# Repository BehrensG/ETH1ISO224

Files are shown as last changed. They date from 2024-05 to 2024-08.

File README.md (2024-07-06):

<h1>ETH1ISO224</h1>

ETH1ISO224 is a one-channel data acquisition card based on the ISO224 chip. The communication with a PC is over Ethernet. The card supports LAN eXtensions for Instrumentation (LXI) and RAW TCP and UDP connections.

> [!CAUTION]
> This design is still in verification phase. The device requires a calibration and validation to be done.

<h2>DESCRIPTION</h2>

<h3>Device Design</h3>

Key features of the design include:

<ul>
    <li><b>Dimensions</b>: 100 x 45 mm</li>
    <li><b>Power Supply</b>: Operates on a voltage range from 6.5 to 36 VDC (recommended 24 VDC) and includes reverse voltage protection.</li>
    <li><b>Isolation</b>: The ISO224 chip with TBA 1-0513HI provides isolation protection for the rest of the circuit.</li>
    <li><b>MCU</b>: The STM32H743VITx was selected because of its large internal FLASH and RAM memory, support for Ethernet, and internal 16-bit ADC.</li>
    <li><b>ADC</b>: Internal 16 bit ADC, configured in differential mode.</li>
    <li><b>Software</b>: FreeRTOS with lwip and SCPI parser library.</li>
</ul>

<p align="center">3D model rendition for PCB V1.2.</p>
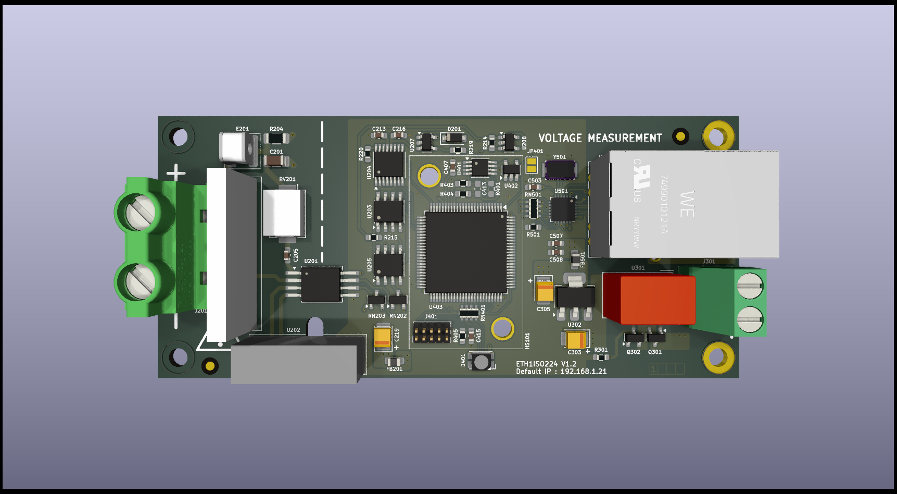
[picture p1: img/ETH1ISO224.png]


<p align="center">Below are the images for the PCB V1.0.</p>


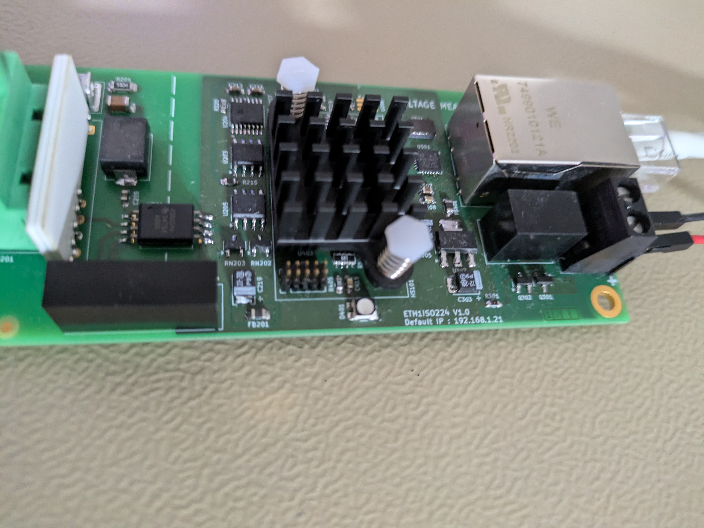
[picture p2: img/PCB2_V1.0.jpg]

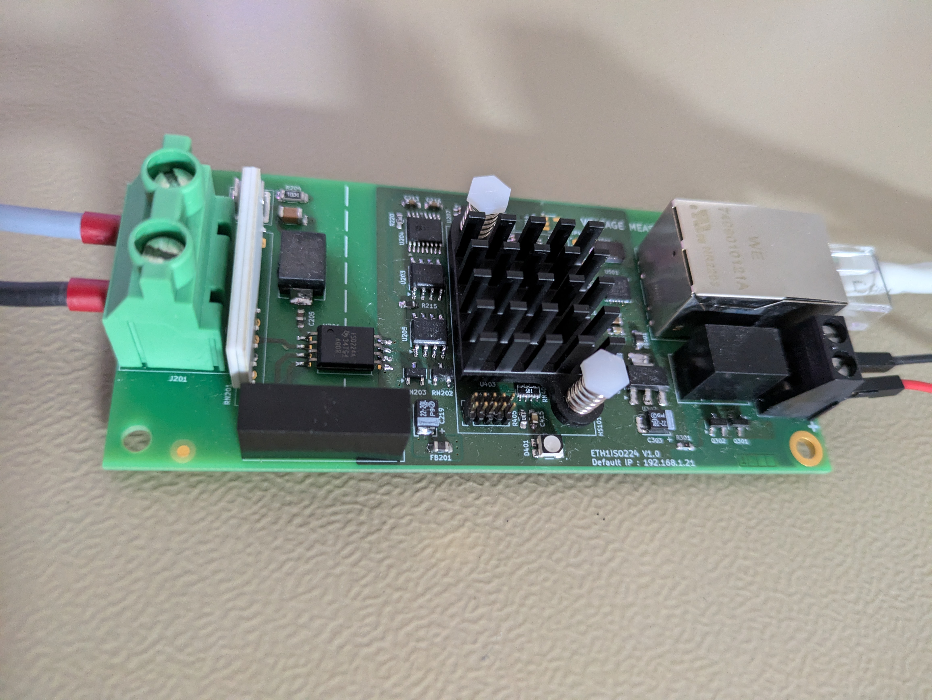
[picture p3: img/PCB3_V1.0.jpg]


<h3>Input voltage</h3>

The PCB was designed for max bipolar 1000V DC measurements. It will divide the input voltage by 100. The user can use 1776-C68xx or SMD resistors to create the voltage divider.

> [!CAUTION]
> The PCB is still in verification. There are no guarantees that it can handle 1000 VDC safely.

<h2>Ethernet connection</h2>

The PCB uses Ethernet to communicate with the PC. The features are :

<h3>LAN eXtensions for Instrumentation (LXI)</h3>

LAN eXtensions for Instrumentation (LXI) is a standard for connecting and controlling test and measurement instruments via Ethernet. It allows for easy integration, remote access, and simplified configuration, enhancing the flexibility and scalability of automated test systems.

> [!WARNING]  
> This device does not guarantee full compliance with the LXI standard. The implementation was based on available documentation and observations of an LXI-compliant device.

> [!TIP]
> To use the LXI features the user needs to use a VISA API. In the examples below, the R&S VISA Tools where uses. 

<h4><p align="center">Device autodetect with multicast DNS (mDNS).</p></h4>
<hr>
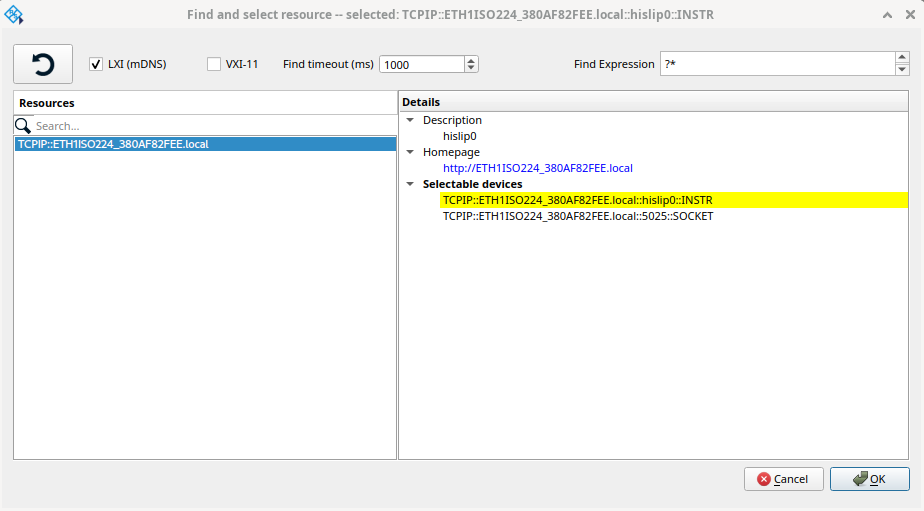
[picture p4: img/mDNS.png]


<h4><p align="center">Support for High Speed LAN Instrument Protocol (HiSLIP).</p></h4>
<hr>
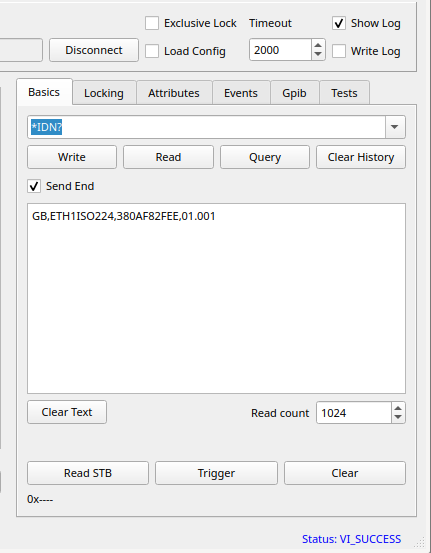
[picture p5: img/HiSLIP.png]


<h4><p align="center">Web interface</p></h4>
<hr>
The device website provides the ability to obtain device information, make measurements, and configure the device. Additionally, it offers a manual with all SCPI commands.

> [!WARNING]
> The website was tested only with Google Chrome  Browser.

<h5><p align="center">Device Home Page</p></h5>
<hr>
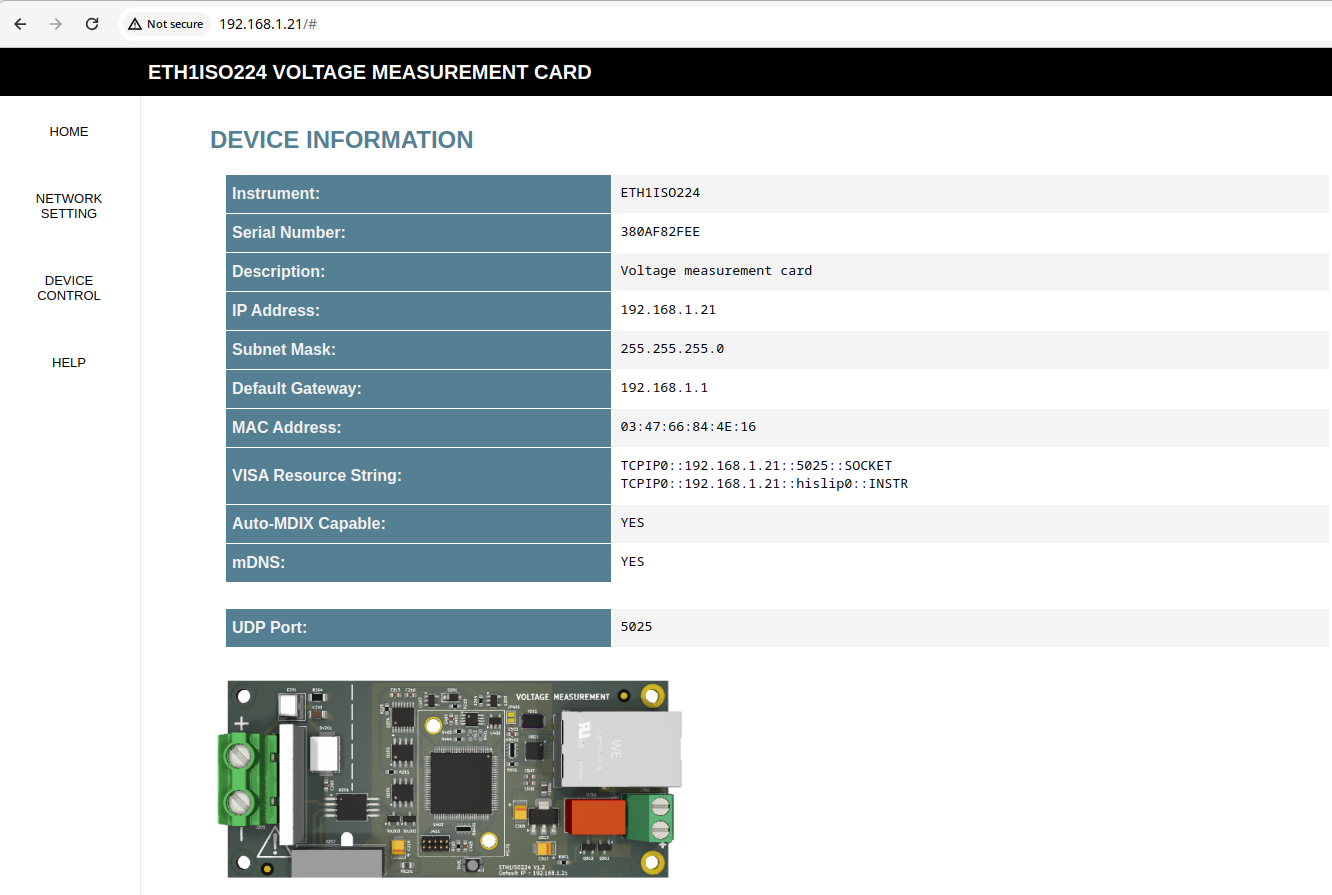
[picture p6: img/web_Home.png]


<h5><p align="center">Device Network Setup</p></h5>
<hr>
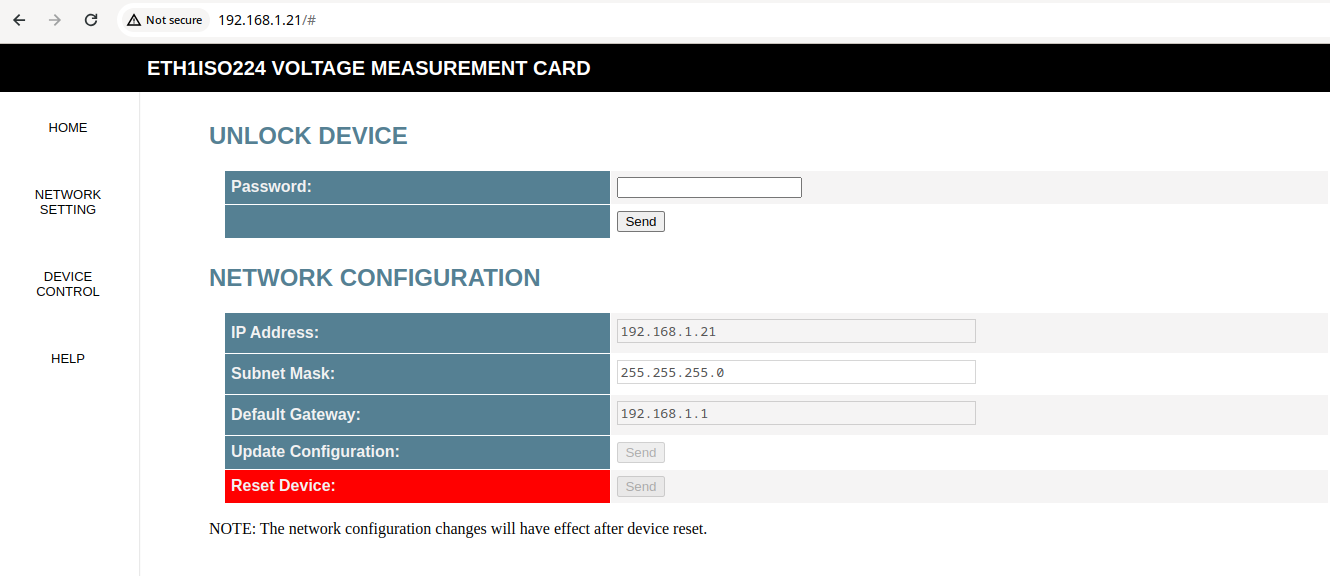
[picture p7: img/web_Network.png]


<h5><p align="center">Device Control</p></h5>
<hr>
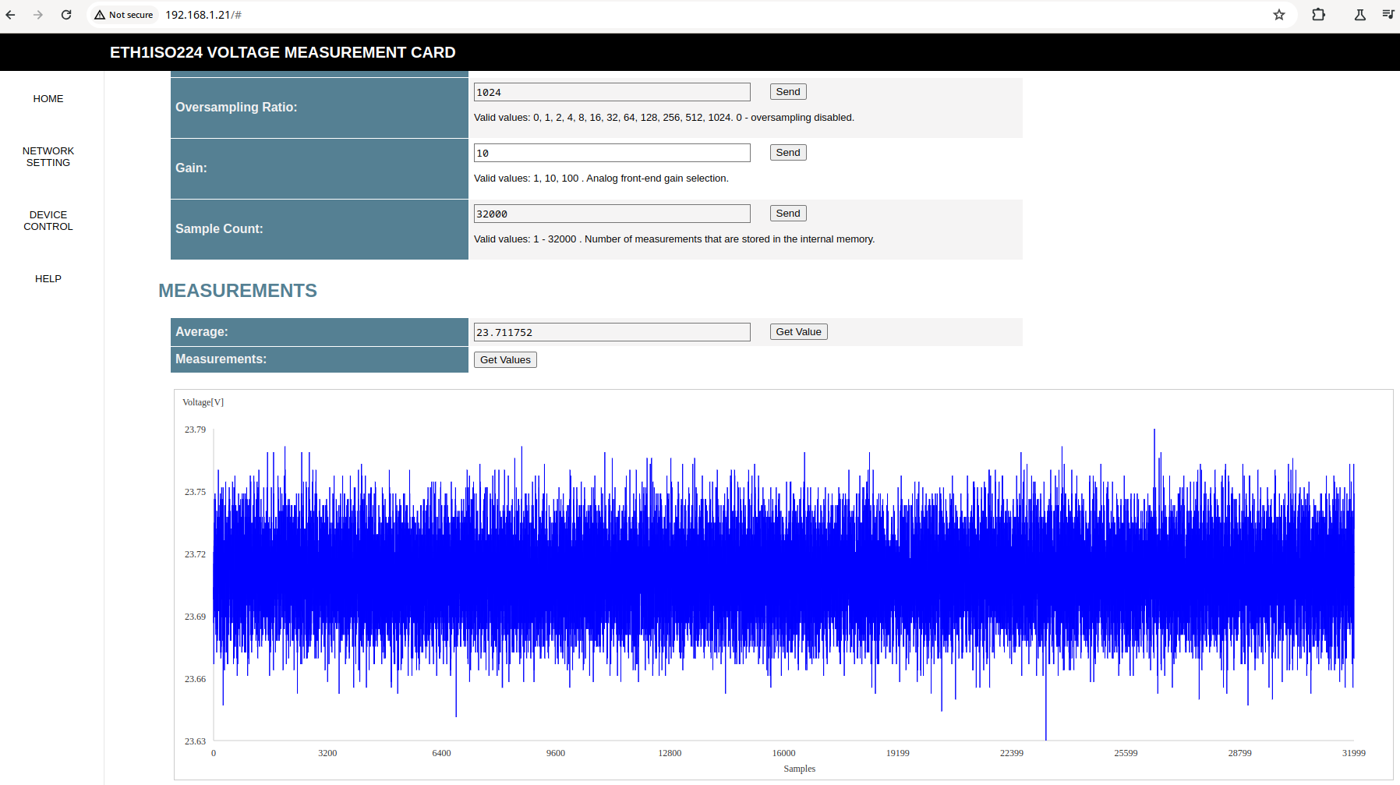
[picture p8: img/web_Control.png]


<h5><p align="center">Device Help</p></h5>
<hr>
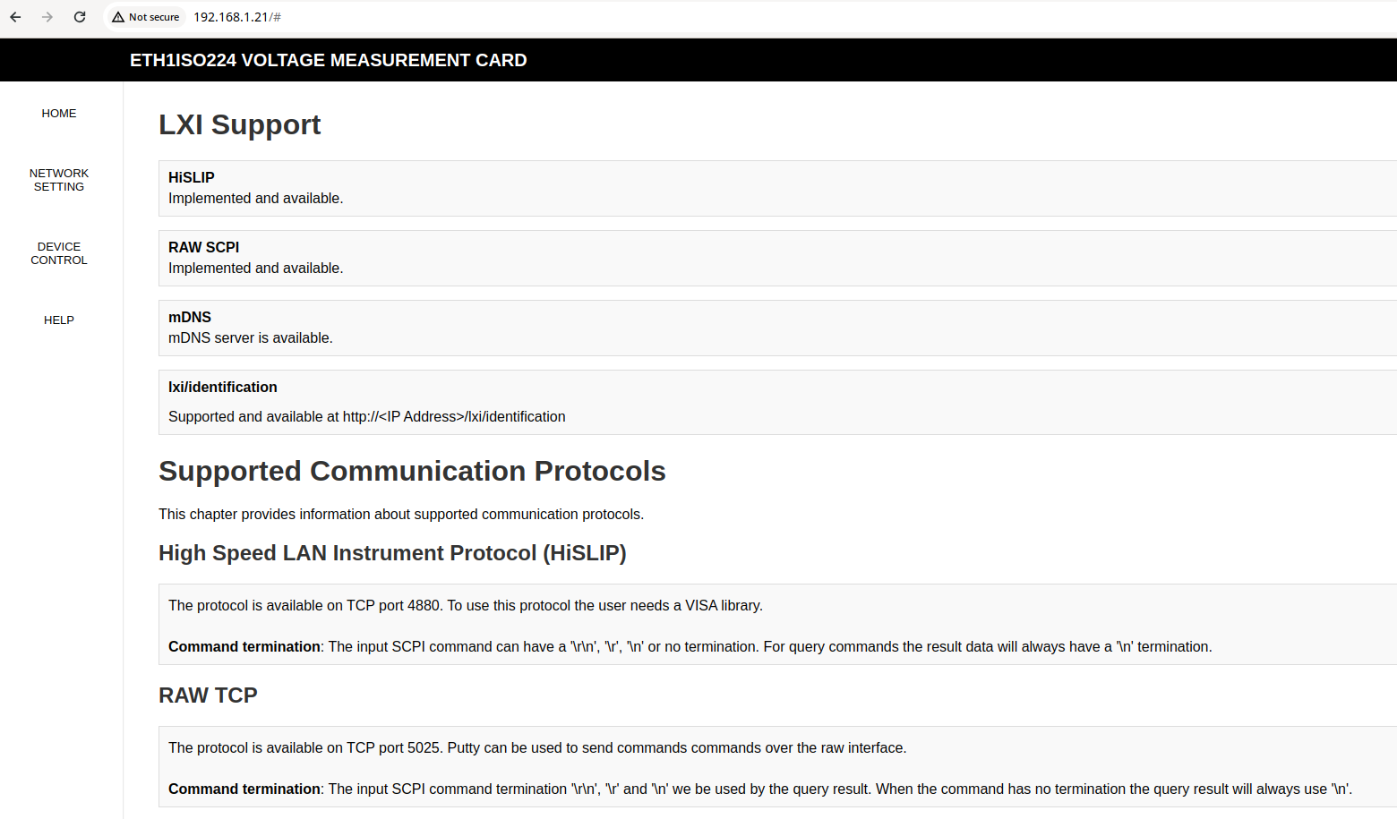
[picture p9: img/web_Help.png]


<h5><p align="center">Device Service</p></h5>
<hr>
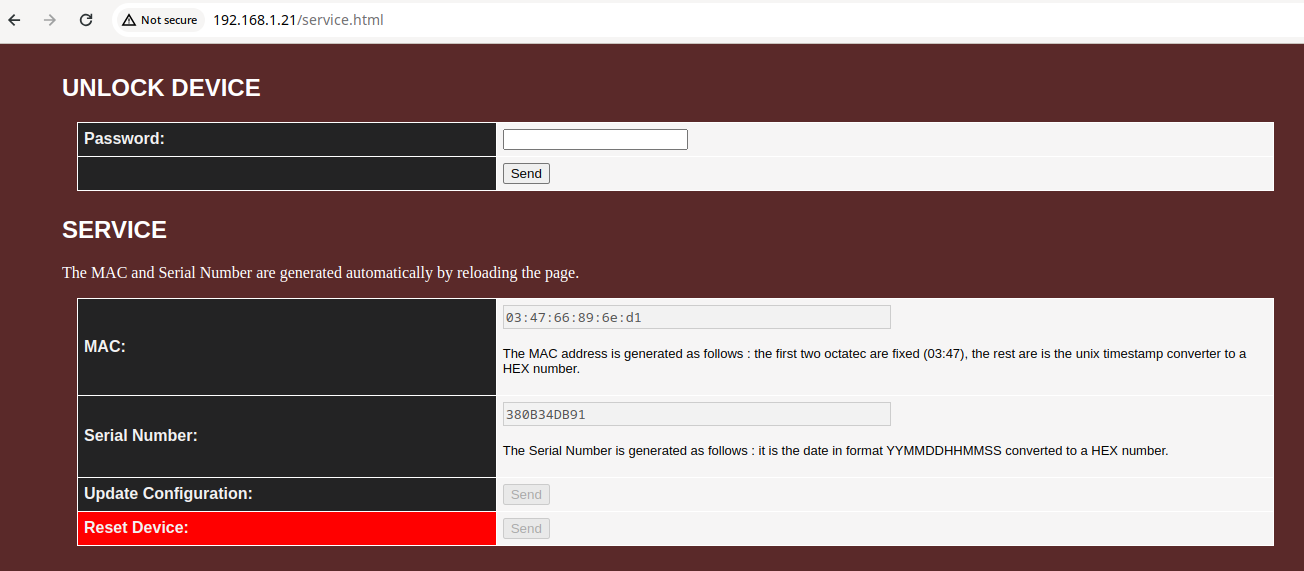
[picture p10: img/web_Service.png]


<h3>RAW TCP</h3>
The user can connect to the device directly over the TCP 5025 port.

<h5><p align="center">Using netcat</p></h5>
<hr>


<h5><p align="center">Using putty</p></h5>
<hr>
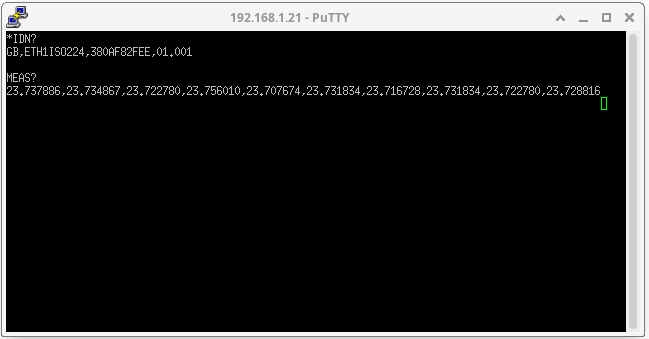
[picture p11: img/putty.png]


<h3>RAW UDP</h3>
The user can connect to the device directly via UDP port 5025. Over UDP, there is a very limited set of SCPI commands available for measurement readout.

> [!WARNING]
> The RAW UDP connection is not part of the LXI standard, it is device specific.

<h5><p align="center">Using netcat</p></h5>
<hr>


<h2>Links</h2>

<ul>
    <li><a href="https://www.ti.com/product/ISO224" target="_blank">ISO224</a></li>
    <li><a href="https://www.lxistandard.org/" target="_blank">LAN eXtensions for Instrumentation</a></li>
    <li><a href="https://www.ivifoundation.org/specifications/default.html" target="_blank">High Speed LAN Instrument Protocol (HiSLIP)</a></li>
    <li><a href="https://en.wikipedia.org/wiki/Virtual_instrument_software_architecture" target="_blank">Virtual instrument software architecture (VISA)</a></li>
    <li><a href="https://www.rohde-schwarz.com/us/driver-pages/remote-control/3-visa-and-tools_231388.html" target="_blank">R&S VISA</a></li>
    <li><a href="https://github.com/j123b567/scpi-parser" target="_blank">SCPI Parser</a></li>
   <li><a href="https://github.com/mpaland/printf" target="_blank">A printf / sprintf Implementation for Embedded Systems</a></li>
</ul>

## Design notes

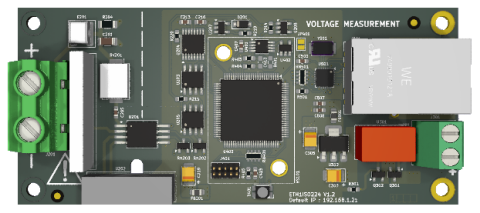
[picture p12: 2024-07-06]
SOFTWARE/ETH1ISO224/Core/BSP/HTTP/fs/img/instrument.png

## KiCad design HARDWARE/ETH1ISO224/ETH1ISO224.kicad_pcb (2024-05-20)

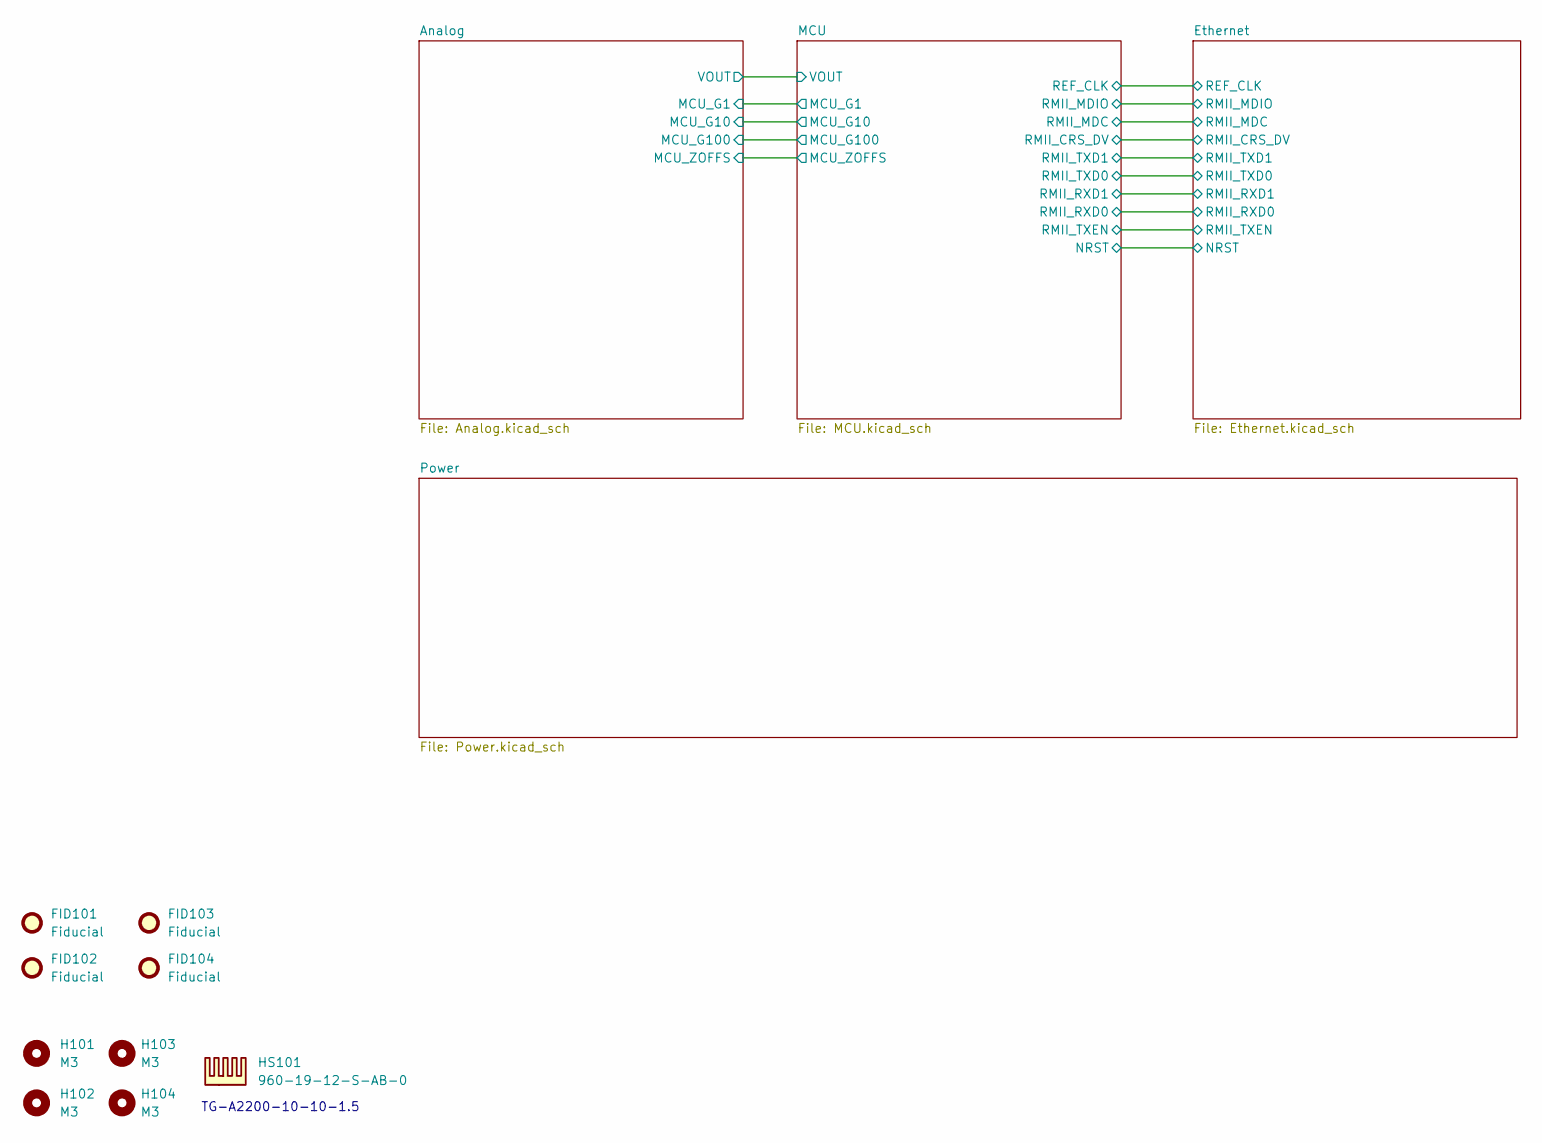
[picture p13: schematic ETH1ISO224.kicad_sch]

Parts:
FID101, FID102, FID103, FID104: Fiducial; Fiducial_1.5mm_Mask3mm
H101, H102: M3; MountingHole_3.2mm_M3_DIN965
H103, H104: M3; MountingHole_3.2mm_M3_DIN965_Pad
HS101: 960-19-12-S-AB-0

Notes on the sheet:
TG-A2200-10-10-1.5

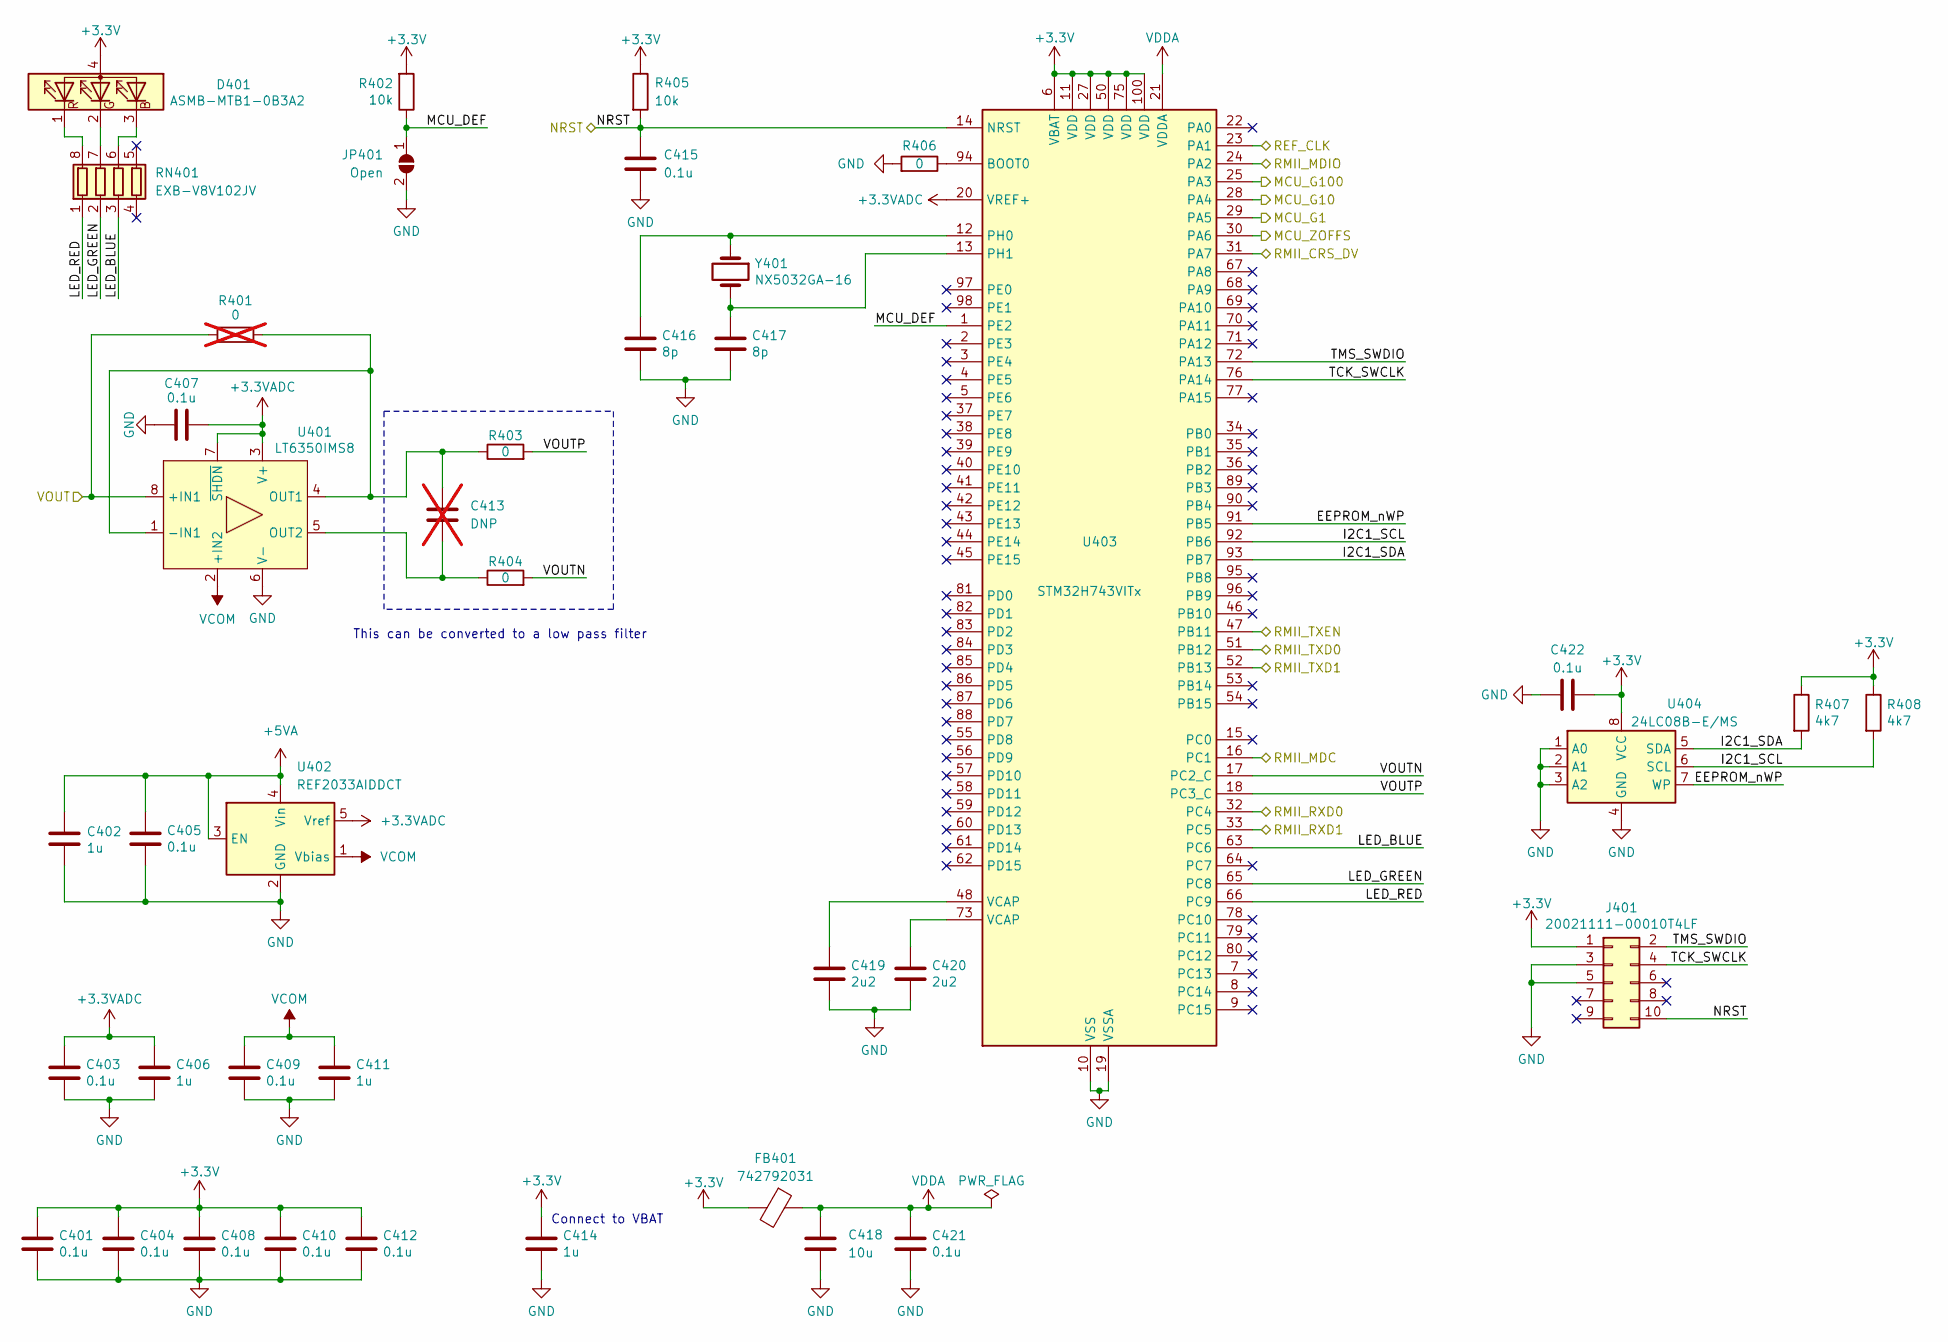
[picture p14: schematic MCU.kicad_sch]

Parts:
C401, C403, C404, C405, C407, C408, C409, C410, C412, C415, C421, C422: 0.1u; C_0603_1608Metric_Pad1.08x0.95mm_HandSolder
C402, C406, C411, C414: 1u; C_0603_1608Metric_Pad1.08x0.95mm_HandSolder
C413: DNP; C_0603_1608Metric_Pad1.08x0.95mm_HandSolder; not fitted
C416, C417: 8p; C_0603_1608Metric_Pad1.08x0.95mm_HandSolder
C418: 10u; C_0603_1608Metric_Pad1.08x0.95mm_HandSolder
C419, C420: 2u2; C_0603_1608Metric_Pad1.08x0.95mm_HandSolder
D401: ASMB-MTB1-0B3A2; LED_Avago_PLCC4_3.2x2.8mm_CW
FB401: 742792031; L_0805_2012Metric_Pad1.05x1.20mm_HandSolder
J401: 20021111-00010T4LF; PinHeader_2x05_P1.27mm_Vertical
JP401: Open; SolderJumper-2_P1.3mm_Open_Pad1.0x1.5mm
R401: 0; R_0603_1608Metric_Pad0.98x0.95mm_HandSolder; not fitted
R402, R405: 10k; R_0603_1608Metric_Pad0.98x0.95mm_HandSolder
R403, R404, R406: 0; R_0603_1608Metric_Pad0.98x0.95mm_HandSolder
R407, R408: 4k7; R_0603_1608Metric_Pad0.98x0.95mm_HandSolder
RN401: EXB-V8V102JV; R_Array_Concave_4x0603
U401: LT6350IMS8; MSOP-8_3x3mm_P0.65mm
U402: REF2033AIDDCT; SOT-23-5
U403: STM32H743VITx; LQFP-100_14x14mm_P0.5mm
U404: 24LC08B-E/MS; MSOP-8_3x3mm_P0.65mm
Y401: NX5032GA-16; NX5032GA

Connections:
+3.3V: C401.1, C404.1, C408.1, C410.1, C412.1, C414.1, C422.2, D401.4 (A), FB401.2, J401.1, R402.2, R405.1, R407.1, R408.1, U403.6 (VBAT), U403.11 (VDD), U403.27 (VDD), U403.50 (VDD), U403.75 (VDD), U403.100 (VDD), U404.8 (VCC); also elsewhere on the board
+3.3VADC: C403.1, C406.1, C407.1, U401.3 (V+), U401.7 (~SHDN), U402.5 (Vref), U403.20 (VREF+)
+5VA: C402.1, C405.1, U402.3 (EN), U402.4 (Vin); also elsewhere on the board
/Analog/MCU_G1: U403.29 (PA5); also elsewhere on the board
/Analog/MCU_G10: U403.28 (PA4); also elsewhere on the board
/Analog/MCU_G100: U403.25 (PA3); also elsewhere on the board
/Analog/MCU_ZOFFS: U403.30 (PA6); also elsewhere on the board
/Analog/VOUT: R401.1, U401.8 (+IN1); also elsewhere on the board
/Ethernet/REF_CLK: U403.23 (PA1); also elsewhere on the board
/Ethernet/RMII_CRS_DV: U403.31 (PA7); also elsewhere on the board
/Ethernet/RMII_MDC: U403.16 (PC1); also elsewhere on the board
/Ethernet/RMII_MDIO: U403.24 (PA2); also elsewhere on the board
/Ethernet/RMII_RXD0: U403.32 (PC4); also elsewhere on the board
/Ethernet/RMII_RXD1: U403.33 (PC5); also elsewhere on the board
/Ethernet/RMII_TXD0: U403.51 (PB12); also elsewhere on the board
/Ethernet/RMII_TXD1: U403.52 (PB13); also elsewhere on the board
/Ethernet/RMII_TXEN: U403.47 (PB11); also elsewhere on the board
/MCU/EEPROM_nWP: U403.91 (PB5), U404.7 (WP)
/MCU/I2C1_SCL: R408.2, U403.92 (PB6), U404.6 (SCL)
/MCU/I2C1_SDA: R407.2, U403.93 (PB7), U404.5 (SDA)
/MCU/LED_BLUE: RN401.3 (R3.1), U403.63 (PC6)
/MCU/LED_GREEN: RN401.2 (R2.1), U403.65 (PC8)
/MCU/LED_RED: RN401.1 (R1.1), U403.66 (PC9)
/MCU/MCU_DEF: JP401.1 (A), R402.1, U403.1 (PE2)
/MCU/NRST: C415.1, J401.10, R405.2, U403.14 (NRST); also elsewhere on the board
/MCU/TCK_SWCLK: J401.4, U403.76 (PA14)
/MCU/TMS_SWDIO: J401.2, U403.72 (PA13)
/MCU/VOUTN: R404.2, U403.17 (PC2_C)
/MCU/VOUTP: R403.2, U403.18 (PC3_C)
GND: C401.2, C402.2, C403.2, C404.2, C405.2, C406.2, C407.2, C408.2, C409.2, C410.2, C411.2, C412.2, C414.2, C415.2, C416.2, C417.2, C418.2, C419.2, C420.2, C421.2, C422.1, J401.3, J401.5, JP401.2 (B), R406.2, U401.6 (V-), U402.2 (GND), U403.10 (VSS), U403.19 (VSSA), U403.26 (VSS), U403.49 (VSS), U403.74 (VSS), U403.99 (VSS), U404.1 (A0), U404.2 (A1), U404.3 (A2), U404.4 (GND); also elsewhere on the board
unnamed: C419.1, U403.48 (VCAP)
unnamed: C420.1, U403.73 (VCAP)
unnamed: D401.3 (BK), RN401.6 (R3.2)
unnamed: D401.2 (GK), RN401.7 (R2.2)
unnamed: D401.1 (RK), RN401.8 (R1.2)
unnamed: C413.1, R401.2, R403.1, U401.1 (-IN1), U401.4 (OUT1)
unnamed: C413.2, R404.1, U401.5 (OUT2)
unnamed: R406.1, U403.94 (BOOT0)
unnamed: C416.1, U403.12 (PH0), Y401.1
unnamed: C417.1, U403.13 (PH1), Y401.2
VCOM: C409.1, C411.1, U401.2 (+IN2), U402.1 (Vbias); also elsewhere on the board
VDDA: C418.1, C421.1, FB401.1, U403.21 (VDDA)

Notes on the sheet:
This can be converted to a low pass filter
Connect to VBAT

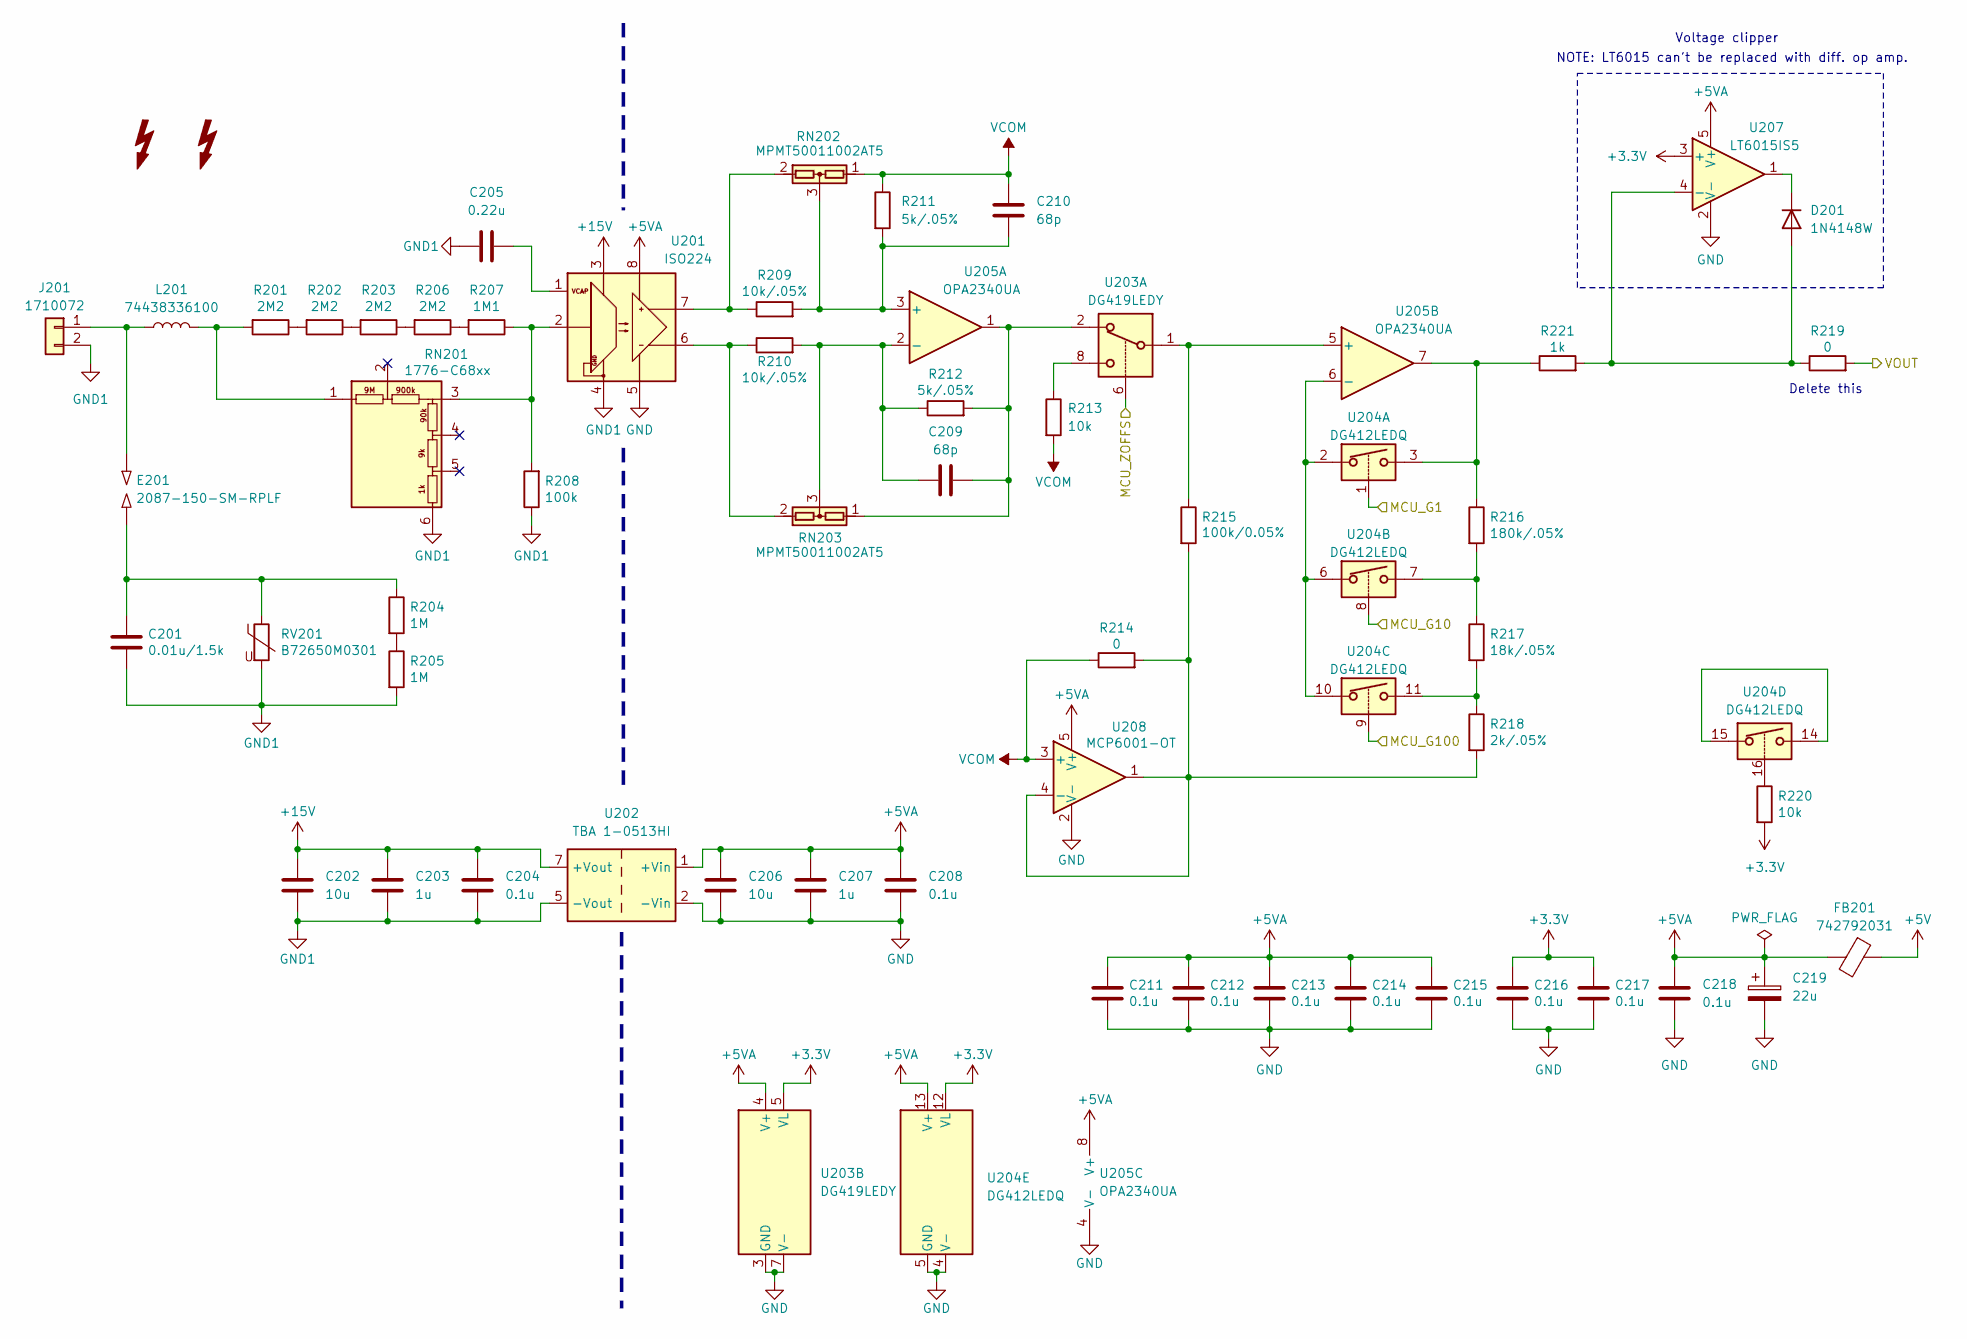
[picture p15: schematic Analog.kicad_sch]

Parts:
C201: 0.01u/1.5k; C_1206_3216Metric_Pad1.33x1.80mm_HandSolder
C202, C206: 10u; C_1206_3216Metric_Pad1.33x1.80mm_HandSolder
C203, C207: 1u; C_0603_1608Metric_Pad1.08x0.95mm_HandSolder
C204, C208, C211, C212, C213, C214, C215, C216, C217, C218: 0.1u; C_0603_1608Metric_Pad1.08x0.95mm_HandSolder
C205: 0.22u; C_0603_1608Metric_Pad1.08x0.95mm_HandSolder
C209, C210: 68p; C_0603_1608Metric_Pad1.08x0.95mm_HandSolder
C219: 22u; CP_EIA-3528-21_Kemet-B_Pad1.50x2.35mm_HandSolder
D201: 1N4148W; D_SOD-123
E201: 2087-150-SM-RPLF; 2087
FB201: 742792031; L_0805_2012Metric_Pad1.05x1.20mm_HandSolder
J201: 1710072
L201: 74438336100; L_Wuerth_MAPI-3015
R201, R202, R203, R206: 2M2; R_1206_3216Metric_Pad1.30x1.75mm_HandSolder
R204, R205: 1M; R_1206_3216Metric_Pad1.30x1.75mm_HandSolder
R207: 1M1; R_1206_3216Metric_Pad1.30x1.75mm_HandSolder
R208: 100k; R_1206_3216Metric_Pad1.30x1.75mm_HandSolder
R209, R210: 10k/.05%; R_0603_1608Metric_Pad0.98x0.95mm_HandSolder
R211, R212: 5k/.05%; R_0603_1608Metric_Pad0.98x0.95mm_HandSolder
R213, R220: 10k; R_0603_1608Metric_Pad0.98x0.95mm_HandSolder
R214, R219: 0; R_0603_1608Metric_Pad0.98x0.95mm_HandSolder
R215: 100k/0.05%; R_0603_1608Metric_Pad0.98x0.95mm_HandSolder
R216: 180k/.05%; R_0603_1608Metric_Pad0.98x0.95mm_HandSolder
R217: 18k/.05%; R_0603_1608Metric_Pad0.98x0.95mm_HandSolder
R218: 2k/.05%; R_0603_1608Metric_Pad0.98x0.95mm_HandSolder
R221: 1k; R_0603_1608Metric_Pad0.98x0.95mm_HandSolder
RN201: 1776-C68xx
RN202, RN203: MPMT50011002AT5; SOT-23
RV201: B72650M0301; Varistor_Panasonic_VF
SYM201, SYM202: SYM_Flash_Small; Symbol_Attention_Triangle_8x7mm_Copper
U201: ISO224; SSO-8_6.8x5.9mm_P1.27mm_Clearance8mm
U202: TBA 1-0513HI; TBA 1HI
U203: DG419LEDY; SOIC-8_3.9x4.9mm_P1.27mm
U204: DG412LEDQ; TSSOP-16_4.4x5mm_P0.65mm
U205: OPA2340UA; SOIC-8_3.9x4.9mm_P1.27mm
U207: LT6015IS5; SOT-23-5
U208: MCP6001-OT; SOT-23-5

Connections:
+3.3V: C216.1, C217.1, R220.2, U203.5 (VL), U204.12 (VL), U207.3 (+); also elsewhere on the board
+5V: FB201.1; also elsewhere on the board
+5VA: C206.1, C207.1, C208.1, C211.1, C212.1, C213.1, C214.1, C215.1, C218.1, C219.1, FB201.2, U201.8 (VDD2), U202.1 (+Vin), U203.4 (V+), U204.13 (V+), U205.8 (V+), U207.5 (V+), U208.5 (V+); also elsewhere on the board
+15V: C202.1, C203.1, C204.1, U201.3 (VDD1), U202.7 (+Vout)
/Analog/MCU_G1: U204.1; also elsewhere on the board
/Analog/MCU_G10: U204.8; also elsewhere on the board
/Analog/MCU_G100: U204.9; also elsewhere on the board
/Analog/MCU_ZOFFS: U203.6; also elsewhere on the board
/Analog/VOUT: R219.2; also elsewhere on the board
GND: C206.2, C207.2, C208.2, C211.2, C212.2, C213.2, C214.2, C215.2, C216.2, C217.2, C218.2, C219.2, U201.5 (GND2), U202.2 (-Vin), U203.3 (GND), U203.7 (V-), U204.4 (V-), U204.5 (GND), U205.4 (V-), U207.2 (V-), U208.2 (V-); also elsewhere on the board
GND1: C201.2, C202.2, C203.2, C204.2, C205.1, J201.2, R205.2, R208.1, RN201.6 (R5), RV201.2, U201.4 (GND1), U202.5 (-Vout)
unnamed: C201.1, E201.1, R204.1, RV201.1
unnamed: C209.2, R212.2, RN203.1, U203.2, U205.1
unnamed: D201.2 (A), R219.1, R221.2, U207.4 (-)
unnamed: D201.1 (K), U207.1
unnamed: E201.2, J201.1, L201.1
unnamed: R201.1, R202.2
unnamed: R202.1, R203.2
unnamed: R203.1, R206.2
unnamed: R204.2, R205.1
unnamed: R206.1, R207.2
unnamed: R213.1, U203.8
unnamed: R216.1, R221.1, U204.3, U205.7
unnamed: R216.2, R217.1, U204.7
unnamed: R217.2, R218.1, U204.11
unnamed: R220.1, U204.16
unnamed: R207.1, R208.2, RN201.3 (R2), U201.2 (IN)
unnamed: L201.2, R201.2, RN201.1 (common)
unnamed: R209.1, RN202.2, U201.7 (OUT+)
unnamed: R210.1, RN203.2, U201.6 (OUT-)
unnamed: C205.2, U201.1 (VCP)
unnamed: U204.14, U204.15
unnamed: C210.1, R209.2, R211.2, RN202.3, U205.3 (+)
unnamed: C209.1, R210.2, R212.1, RN203.3, U205.2 (-)
unnamed: R215.1, U203.1, U205.5 (+)
unnamed: U204.2, U204.6, U204.10, U205.6 (-)
unnamed: R214.2, R215.2, R218.2, U208.1, U208.4 (-)
VCOM: C210.2, R211.1, R213.2, R214.1, RN202.1, U208.3 (+); also elsewhere on the board

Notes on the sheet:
Voltage clipper
Delete this
NOTE: LT6015 can't be replaced with diff. op amp.

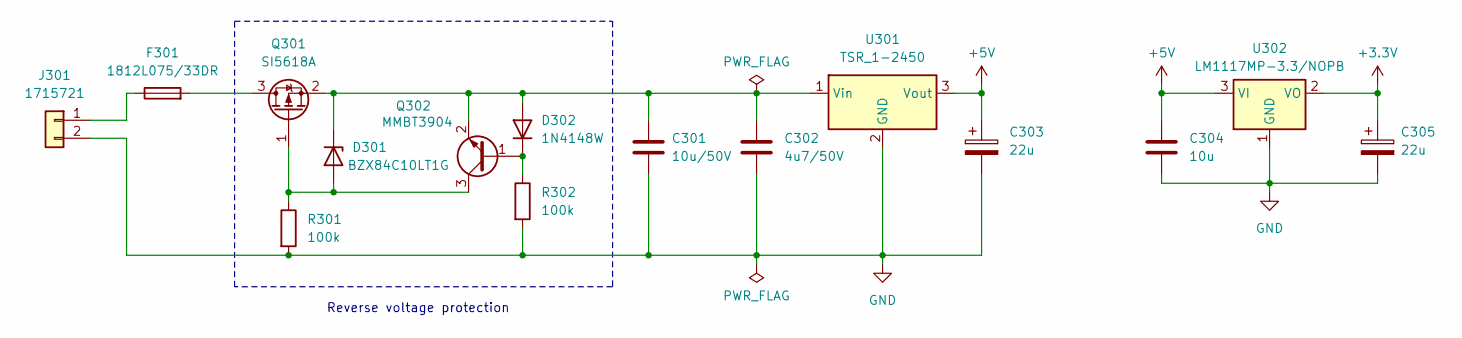
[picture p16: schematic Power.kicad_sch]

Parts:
C301: 10u/50V; C_1206_3216Metric_Pad1.33x1.80mm_HandSolder
C302: 4u7/50V; C_1206_3216Metric_Pad1.33x1.80mm_HandSolder
C303, C305: 22u; CP_EIA-3528-21_Kemet-B_Pad1.50x2.35mm_HandSolder
C304: 10u; C_1206_3216Metric_Pad1.33x1.80mm_HandSolder
D301: BZX84C10LT1G; SOT-23
D302: 1N4148W; D_SOD-123
F301: 1812L075/33DR; Fuse_1812_4532Metric_Pad1.30x3.40mm_HandSolder
J301: 1715721; TerminalBlock_Phoenix_MKDS-1,5-2_1x02_P5.00mm_Horizontal
Q301: SI5618A; SOT-23
Q302: MMBT3904; SOT-23
R301, R302: 100k; R_0603_1608Metric_Pad0.98x0.95mm_HandSolder
U301: TSR_1-2450; Converter_DCDC_TRACO_TSR-1_THT
U302: LM1117MP-3.3/NOPB; SOT-223-3_TabPin2

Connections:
+3.3V: C305.1, U302.2 (VO); also elsewhere on the board
+5V: C303.1, C304.1, U301.3 (Vout), U302.3 (VI); also elsewhere on the board
GND: C301.2, C302.2, C303.2, C304.2, C305.2, J301.2, R301.2, R302.2, U301.2 (GND), U302.1 (GND); also elsewhere on the board
unnamed: D301.1 (A), Q301.1 (G), Q302.3 (C), R301.1
unnamed: C301.1, C302.1, D301.3 (K), D302.2 (A), Q301.2 (S), Q302.2 (E), U301.1 (Vin)
unnamed: D302.1 (K), Q302.1 (B), R302.1
unnamed: F301.1, J301.1
unnamed: F301.2, Q301.3 (D)

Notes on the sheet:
Reverse voltage protection

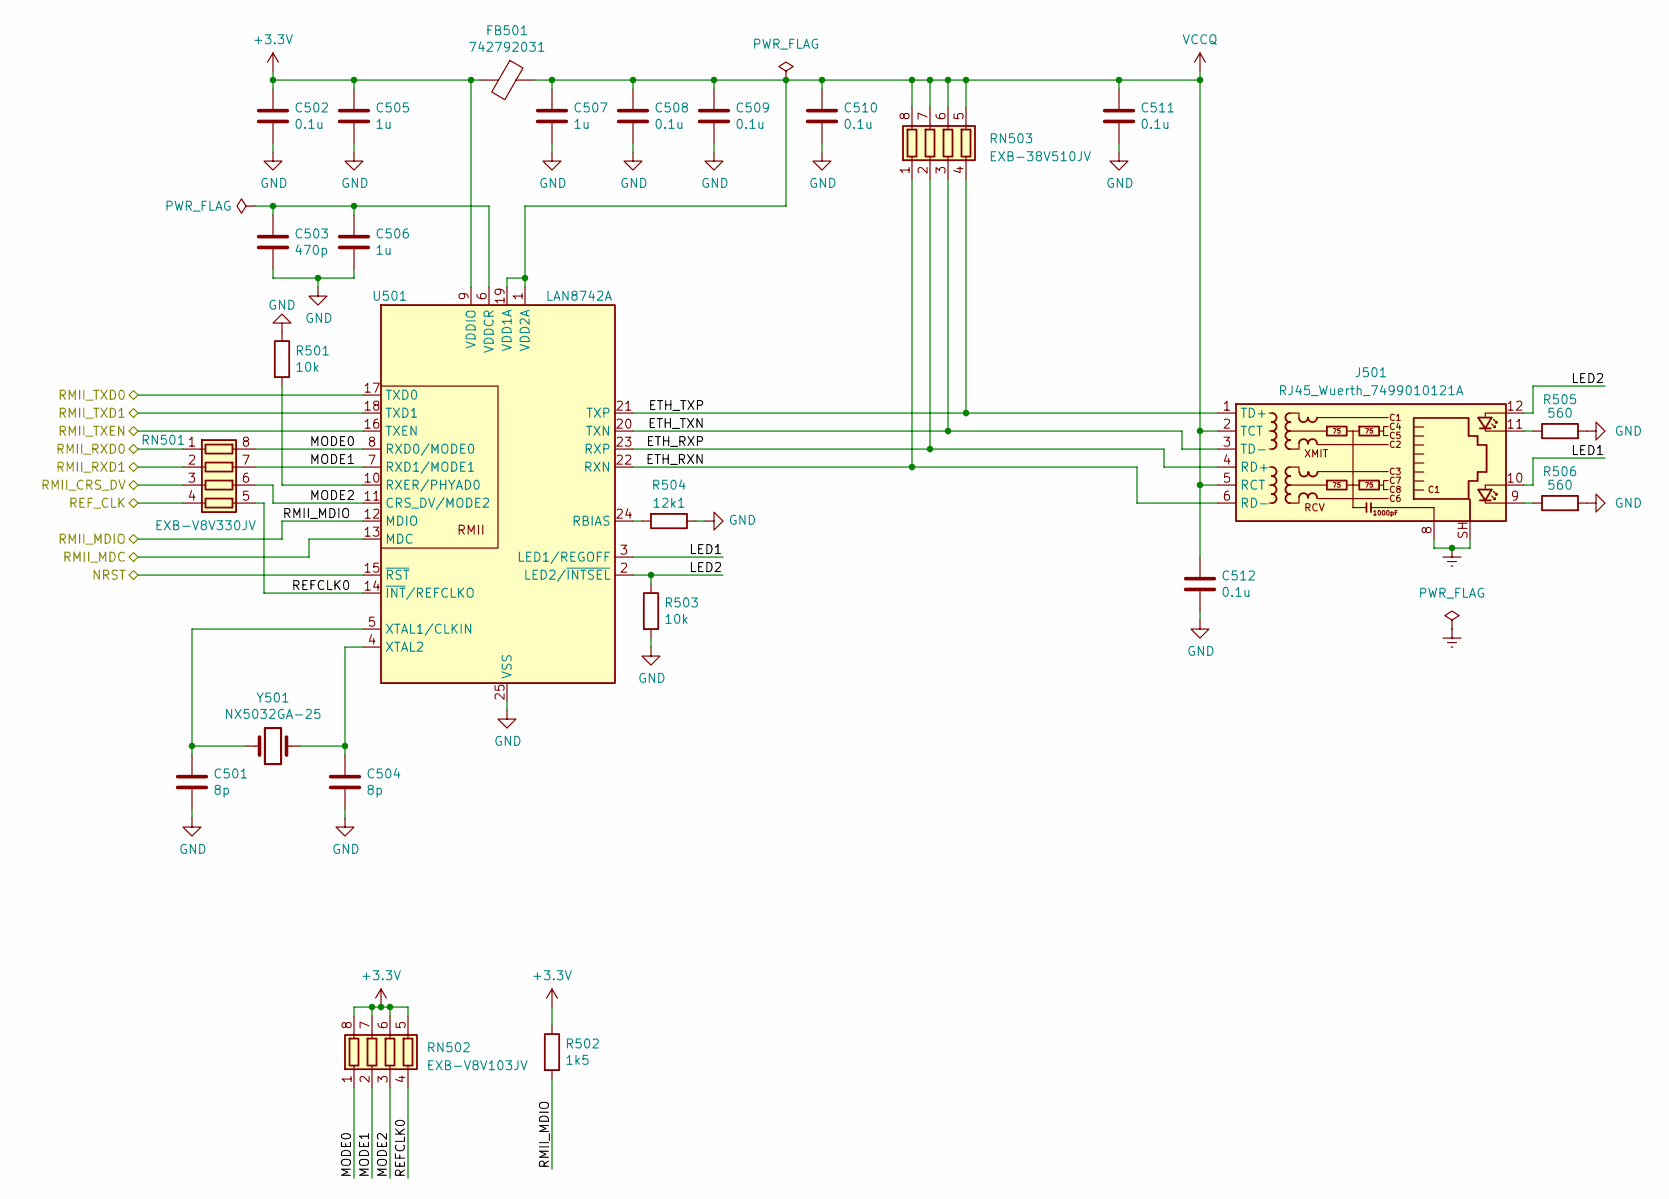
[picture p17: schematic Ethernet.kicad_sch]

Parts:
C501, C504: 8p; C_0603_1608Metric_Pad1.08x0.95mm_HandSolder
C502, C508, C509, C510, C511, C512: 0.1u; C_0603_1608Metric_Pad1.08x0.95mm_HandSolder
C503: 470p; C_0603_1608Metric_Pad1.08x0.95mm_HandSolder
C505, C506, C507: 1u; C_0603_1608Metric_Pad1.08x0.95mm_HandSolder
FB501: 742792031; L_0805_2012Metric_Pad1.05x1.20mm_HandSolder
J501: RJ45_Wuerth_7499010121A; RJ45_Wuerth_7499010121A_Horizontal
R501, R503: 10k; R_0603_1608Metric_Pad0.98x0.95mm_HandSolder
R502: 1k5; R_0603_1608Metric_Pad0.98x0.95mm_HandSolder
R504: 12k1; R_0603_1608Metric_Pad0.98x0.95mm_HandSolder
R505, R506: 560; R_0603_1608Metric_Pad0.98x0.95mm_HandSolder
RN501: EXB-V8V330JV; R_Array_Concave_4x0603
RN502: EXB-V8V103JV; R_Array_Concave_4x0603
RN503: EXB-38V510JV; R_Array_Concave_4x0603
U501: LAN8742A; VQFN-24-1EP_4x4mm_P0.5mm_EP2.5x2.5mm_ThermalVias
Y501: NX5032GA-25; NX5032GA

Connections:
+3.3V: C502.1, C505.1, FB501.2, R502.1, RN502.5 (R4.2), RN502.6 (R3.2), RN502.7 (R2.2), RN502.8 (R1.2), U501.9 (VDDIO); also elsewhere on the board
/Ethernet/ETH_RXN: J501.6 (RD-), RN503.1 (R1.1), U501.22 (RXN)
/Ethernet/ETH_RXP: J501.4 (RD+), RN503.2 (R2.1), U501.23 (RXP)
/Ethernet/ETH_TXN: J501.3 (TD-), RN503.3 (R3.1), U501.20 (TXN)
/Ethernet/ETH_TXP: J501.1 (TD+), RN503.4 (R4.1), U501.21 (TXP)
/Ethernet/LED1: J501.10, U501.3 (LED1/REGOFF)
/Ethernet/LED2: J501.12, R503.1, U501.2 (LED2/~INTSEL)
/Ethernet/MODE0: RN501.8 (R1.2), RN502.1 (R1.1), U501.8 (RXD0/MODE0)
/Ethernet/MODE1: RN501.7 (R2.2), RN502.2 (R2.1), U501.7 (RXD1/MODE1)
/Ethernet/MODE2: RN501.6 (R3.2), RN502.3 (R3.1), U501.11 (CRS_DV/MODE2)
/Ethernet/REFCLK0: RN501.5 (R4.2), RN502.4 (R4.1), U501.14 (~INT/REFCLKO)
/Ethernet/REF_CLK: RN501.4 (R4.1); also elsewhere on the board
/Ethernet/RMII_CRS_DV: RN501.3 (R3.1); also elsewhere on the board
/Ethernet/RMII_MDC: U501.13 (MDC); also elsewhere on the board
/Ethernet/RMII_MDIO: R502.2, U501.12 (MDIO); also elsewhere on the board
/Ethernet/RMII_RXD0: RN501.1 (R1.1); also elsewhere on the board
/Ethernet/RMII_RXD1: RN501.2 (R2.1); also elsewhere on the board
/Ethernet/RMII_TXD0: U501.17 (TXD0); also elsewhere on the board
/Ethernet/RMII_TXD1: U501.18 (TXD1); also elsewhere on the board
/Ethernet/RMII_TXEN: U501.16 (TXEN); also elsewhere on the board
/MCU/NRST: U501.15 (~RST); also elsewhere on the board
Earth: J501.8, J501.SH
GND: C501.2, C502.2, C503.2, C504.2, C505.2, C506.2, C507.2, C508.2, C509.2, C510.2, C511.2, C512.2, R501.1, R503.2, R504.1, R505.2, R506.2, U501.25 (VSS); also elsewhere on the board
unnamed: J501.9, R506.1
unnamed: J501.11, R505.1
unnamed: R504.2, U501.24 (RBIAS)
unnamed: R501.2, U501.10 (RXER/PHYAD0)
unnamed: C503.1, C506.1, U501.6 (VDDCR)
unnamed: C501.1, U501.5 (XTAL1/CLKIN), Y501.2
unnamed: C504.1, U501.4 (XTAL2), Y501.1
VCCQ: C507.1, C508.1, C509.1, C510.1, C511.1, C512.1, FB501.1, J501.2 (TCT), J501.5 (RCT), RN503.5 (R4.2), RN503.6 (R3.2), RN503.7 (R2.2), RN503.8 (R1.2), U501.1 (VDD2A), U501.19 (VDD1A)

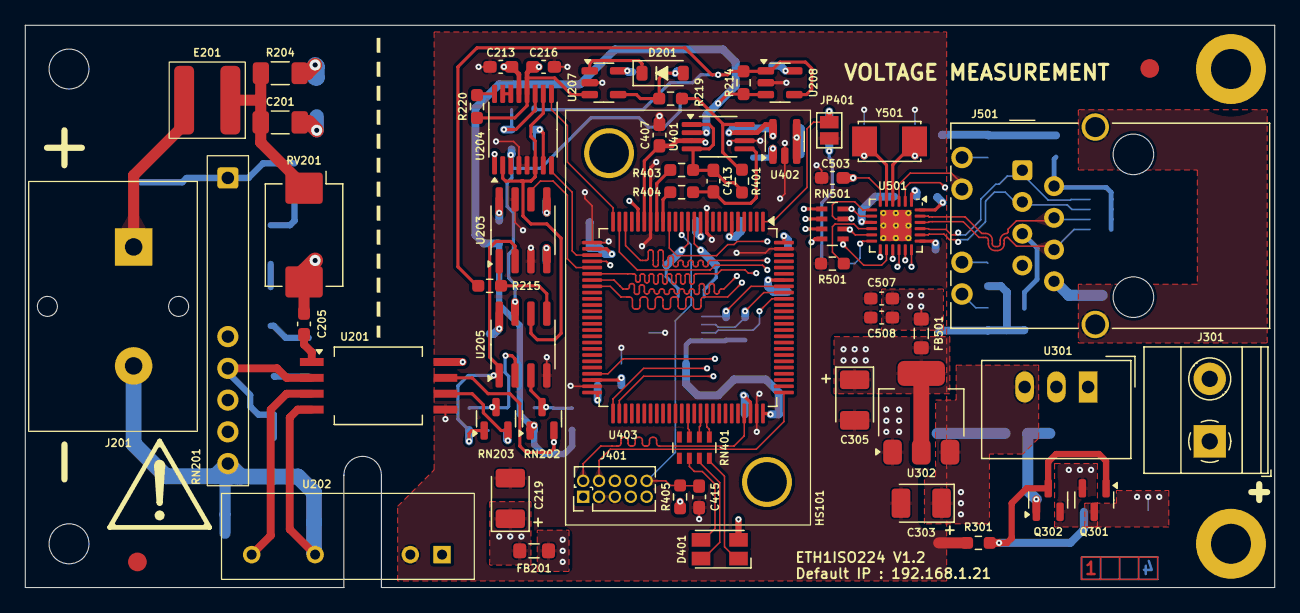
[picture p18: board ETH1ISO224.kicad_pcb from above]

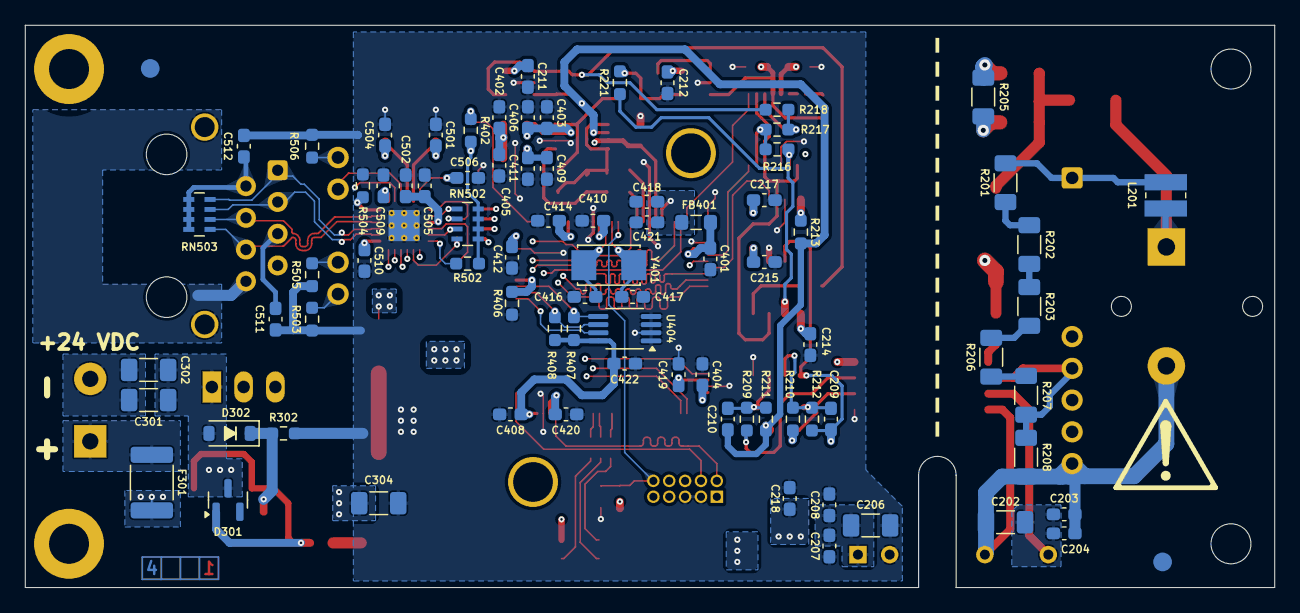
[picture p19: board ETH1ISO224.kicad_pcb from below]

Board: 4 copper layers, 100.0 x 45.0 mm, 147 parts (83 on the bottom side), 95 nets.

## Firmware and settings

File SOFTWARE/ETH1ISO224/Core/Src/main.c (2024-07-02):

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
/* Includes ------------------------------------------------------------------*/
#include "main.h"
#include "cmsis_os.h"
#include "lwip.h"

/* USER CODE BEGIN Includes */
#include "SCPI_Server.h"
#include "BSP.h"
#include "LED.h"
#include "ADC.h"
#include "UDP.h"


#include "multicastDNS.h"
#include "HTTP_Task.h"
#include "HiSLIP_Task.h"
/* USER CODE END Includes */

/* USER CODE BEGIN PD */
static void nop_delay(void)
{
	for(uint32_t i = 0; i < 5000000; i++)
	{
		__NOP();
	}
}
/* USER CODE END PD */

ADC_HandleTypeDef hadc3;
DMA_HandleTypeDef hdma_adc3;

I2C_HandleTypeDef hi2c1;

TIM_HandleTypeDef htim3;

osThreadId defaultTaskHandle;
uint32_t defaultTaskBuffer[ 512 ];
osStaticThreadDef_t defaultTaskControlBlock;
/* USER CODE BEGIN PV */
extern bsp_t bsp;
extern bsp_eeprom_t eeprom_default;
extern xQueueHandle QueueLEDHandle;
extern uint16_t adc_data[];

SemaphoreHandle_t MeasMutex;

/* USER CODE END PV */

void SystemClock_Config(void);
void PeriphCommonClock_Config(void);
static void MPU_Config(void);
static void MX_GPIO_Init(void);
static void MX_DMA_Init(void);
static void MX_ADC3_Init(void);
static void MX_I2C1_Init(void);
static void MX_TIM3_Init(void);
void StartDefaultTask(void const * argument);

/**
  * @brief  The application entry point.
  * @retval int
  */
int main(void)
{

  /* USER CODE BEGIN 1 */
	nop_delay(); // Delay to get mDNS working.
  /* USER CODE END 1 */

  /* MPU Configuration--------------------------------------------------------*/
  MPU_Config();

  /* Enable the CPU Cache */

  /* Enable I-Cache---------------------------------------------------------*/
  SCB_EnableICache();

  /* Enable D-Cache---------------------------------------------------------*/
  SCB_EnableDCache();

  /* MCU Configuration--------------------------------------------------------*/

  /* Reset of all peripherals, Initializes the Flash interface and the Systick. */
  HAL_Init();

  /* Configure the system clock */
  SystemClock_Config();

  /* Configure the peripherals common clocks */
  PeriphCommonClock_Config();

  /* Initialize all configured peripherals */
  MX_GPIO_Init();
  MX_DMA_Init();
  MX_ADC3_Init();
  MX_I2C1_Init();
  MX_TIM3_Init();
  /* USER CODE BEGIN 2 */
  LED_Control(BLUE, true);
  HAL_Delay(100);
  BSP_Init();
  ADC_AutoCalibration();
  ADC_InitMemory();

  /* USER CODE END 2 */

  /* USER CODE BEGIN RTOS_MUTEX */
  /* add mutexes, ... */

  MeasMutex = xSemaphoreCreateMutex();

  /* USER CODE END RTOS_MUTEX */

  /* USER CODE BEGIN RTOS_SEMAPHORES */
  /* add semaphores, ... */
  /* USER CODE END RTOS_SEMAPHORES */

  /* USER CODE BEGIN RTOS_TIMERS */
  /* start timers, add new ones, ... */
  /* USER CODE END RTOS_TIMERS */

  /* USER CODE BEGIN RTOS_QUEUES */
  /* add queues, ... */
  QueueLEDHandle = xQueueCreate(1, sizeof(uint32_t));
  /* USER CODE END RTOS_QUEUES */

  /* Create the thread(s) */
  /* definition and creation of defaultTask */
  osThreadStaticDef(defaultTask, StartDefaultTask, osPriorityNormal, 0, 512, defaultTaskBuffer, &defaultTaskControlBlock);
  defaultTaskHandle = osThreadCreate(osThread(defaultTask), NULL);

  /* USER CODE BEGIN RTOS_THREADS */
  /* add threads, ... */
  /* USER CODE END RTOS_THREADS */

  /* Start scheduler */
  osKernelStart();

  /* We should never get here as control is now taken by the scheduler */

  /* Infinite loop */
  /* USER CODE BEGIN WHILE */
  while (1)
  {
    /* USER CODE END WHILE */

    /* USER CODE BEGIN 3 */
  }
  /* USER CODE END 3 */
}

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
/* USER CODE BEGIN Header_StartDefaultTask */
/**
  * @brief  Function implementing the defaultTask thread.
  * @param  argument: Not used
  * @retval None
  */
/* USER CODE END Header_StartDefaultTask */
void StartDefaultTask(void const * argument)
{
  /* init code for LWIP */
  MX_LWIP_Init();
  /* USER CODE BEGIN 5 */

  led_select_t  led_color_status = GREEN;

  if(bsp.default_cfg)
  {
	  led_color_status = BLUE;

  }

  vTaskDelay(pdMS_TO_TICKS(300)); // Need this wait to get lwip to work

  SCPI_CreateTask();
  UDP_CreateTask();

  if(bsp.eeprom.structure.services.hislip)
  {
	  HISLIP_CreateTask();
  }

  if(bsp.eeprom.structure.services.mdns)
  {
	  MDNS_Init();
  }

  HTTP_CreateTask();

  LED_Control(BLUE, false);
  HAL_TIM_Base_Start_IT(&htim3);

  /* Infinite loop */
  for(;;)
  {

	  if(pdTRUE == xQueueReceive(QueueLEDHandle, &led_color_status, 5U))
	  {

	  }
	  else
	  {
		  led_color_status = LED_NONE;
	  }

	  if(bsp.led)
	  {
		  switch(led_color_status)
		  {
		  	  case RED: LED_Toggle(RED, 50, 1); break;
		  	  case GREEN: LED_Toggle(GREEN, 1, 1); break;
		  	  case BLUE: LED_Toggle(BLUE, 1, 1); break;
		  	  default: vTaskDelay(pdMS_TO_TICKS(1)); break;
		  }
	  }
	  else
	  {
		  vTaskDelay(pdMS_TO_TICKS(1));
	  }

  }
  /* USER CODE END 5 */
}

 /* MPU Configuration */

void MPU_Config(void)
{
  MPU_Region_InitTypeDef MPU_InitStruct = {0};

  /* Disables the MPU */
  HAL_MPU_Disable();

  /** Initializes and configures the Region and the memory to be protected
  */
  MPU_InitStruct.Enable = MPU_REGION_ENABLE;
  MPU_InitStruct.Number = MPU_REGION_NUMBER0;
  MPU_InitStruct.BaseAddress = 0x0;
  MPU_InitStruct.Size = MPU_REGION_SIZE_4GB;
  MPU_InitStruct.SubRegionDisable = 0x87;
  MPU_InitStruct.TypeExtField = MPU_TEX_LEVEL0;
  MPU_InitStruct.AccessPermission = MPU_REGION_NO_ACCESS;
  MPU_InitStruct.DisableExec = MPU_INSTRUCTION_ACCESS_DISABLE;
  MPU_InitStruct.IsShareable = MPU_ACCESS_SHAREABLE;
  MPU_InitStruct.IsCacheable = MPU_ACCESS_NOT_CACHEABLE;
  MPU_InitStruct.IsBufferable = MPU_ACCESS_NOT_BUFFERABLE;

  HAL_MPU_ConfigRegion(&MPU_InitStruct);

  /** Initializes and configures the Region and the memory to be protected
  */
  MPU_InitStruct.Number = MPU_REGION_NUMBER1;
  MPU_InitStruct.BaseAddress = 0x30020000;
  MPU_InitStruct.Size = MPU_REGION_SIZE_128KB;
  MPU_InitStruct.SubRegionDisable = 0x0;
  MPU_InitStruct.TypeExtField = MPU_TEX_LEVEL1;
  MPU_InitStruct.AccessPermission = MPU_REGION_FULL_ACCESS;
  MPU_InitStruct.IsShareable = MPU_ACCESS_NOT_SHAREABLE;

  HAL_MPU_ConfigRegion(&MPU_InitStruct);

  /** Initializes and configures the Region and the memory to be protected
  */
  MPU_InitStruct.Number = MPU_REGION_NUMBER2;
  MPU_InitStruct.BaseAddress = 0x30040000;
  MPU_InitStruct.Size = MPU_REGION_SIZE_512B;
  MPU_InitStruct.TypeExtField = MPU_TEX_LEVEL0;
  MPU_InitStruct.IsShareable = MPU_ACCESS_SHAREABLE;
  MPU_InitStruct.IsBufferable = MPU_ACCESS_BUFFERABLE;

  HAL_MPU_ConfigRegion(&MPU_InitStruct);
  /* Enables the MPU */
  HAL_MPU_Enable(MPU_PRIVILEGED_DEFAULT);

}

/**
  * @brief  Period elapsed callback in non blocking mode
  * @note   This function is called  when TIM1 interrupt took place, inside
  * HAL_TIM_IRQHandler(). It makes a direct call to HAL_IncTick() to increment
  * a global variable "uwTick" used as application time base.
  * @param  htim : TIM handle
  * @retval None
  */
void HAL_TIM_PeriodElapsedCallback(TIM_HandleTypeDef *htim)
{
  if (htim->Instance == TIM1) {
    HAL_IncTick();
  }
}

/**
  * @brief  This function is executed in case of error occurrence.
  * @retval None
  */
void Error_Handler(void)
{
  /* USER CODE BEGIN Error_Handler_Debug */
  /* User can add his own implementation to report the HAL error return state */
  __disable_irq();

  LED_Control(GREEN | BLUE, false);

  while (1)
  {
	  LED_Control(RED, true);
  }
  /* USER CODE END Error_Handler_Debug */
}

#ifdef  USE_FULL_ASSERT
/**
  * @brief  Reports the name of the source file and the source line number
  *         where the assert_param error has occurred.
  * @param  file: pointer to the source file name
  * @param  line: assert_param error line source number
  * @retval None
  */
void assert_failed(uint8_t *file, uint32_t line)
{
  /* USER CODE BEGIN 6 */
  /* User can add his own implementation to report the file name and line number,
     ex: printf("Wrong parameters value: file %s on line %d\r\n", file, line) */
  /* USER CODE END 6 */
}
#endif /* USE_FULL_ASSERT */

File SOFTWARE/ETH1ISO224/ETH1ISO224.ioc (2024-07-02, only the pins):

Mcu.UserName=STM32H743VITx
PA1.Signal=ETH_REF_CLK
PA2.Signal=ETH_MDIO
PA3.GPIO_Label=MCU_G100
PA3.Signal=GPIO_Output
PA4.GPIO_Label=MCU_G10
PA4.Signal=GPIO_Output
PA5.GPIO_Label=MCU_G1
PA5.Signal=GPIO_Output
PA6.GPIO_Label=MCU_ZOFFS
PA6.Signal=GPIO_Output
PA7.Signal=ETH_CRS_DV
PB11.Signal=ETH_TX_EN
PB12.Signal=ETH_TXD0
PB13.Signal=ETH_TXD1
PB5.GPIO_Label=EEPROM_nWP
PB5.Signal=GPIO_Output
PB6.Signal=I2C1_SCL
PB7.Signal=I2C1_SDA
PC1.Signal=ETH_MDC
PC2_C.Signal=ADC3_INN1
PC3_C.Signal=ADC3_INP1
PC4.Signal=ETH_RXD0
PC5.Signal=ETH_RXD1
PC6.GPIO_Label=LED_BLUE
PC6.Signal=GPIO_Output
PC8.GPIO_Label=LED_GREEN
PC8.Signal=GPIO_Output
PC9.GPIO_Label=LED_RED
PC9.Signal=GPIO_Output
PE2.GPIO_Label=MCU_DEFAULT
PE2.Signal=GPIO_Input

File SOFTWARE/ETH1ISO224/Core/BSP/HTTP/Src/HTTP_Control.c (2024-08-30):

/*
 * HTTP_Support.c
 *
 *  Created on: Jun 20, 2024
 *      Author: BehrensG
 */

// --------------------------------------------------------------------------------------------------------------------

#include <string.h>
#include <stdint.h>

#include "cmsis_os.h"

#include "HTTP_Task.h"
#include "BSP.h"
#include "DEVICE_INFO.h"
#include "LED.h"
#include "ADC.h"
#include "GPIO.h"
#include "FloatToString.h"

// --------------------------------------------------------------------------------------------------------------------

extern bsp_t bsp;
extern ADC_HandleTypeDef hadc3;
extern char buffer[];
extern float measurements[];
extern SemaphoreHandle_t MeasMutex;
extern TIM_HandleTypeDef htim3;

// --------------------------------------------------------------------------------------------------------------------

#define HTTP_POST_CONTROL_BLINK_LED			0
#define HTTP_GET_RESOLUTION					1
#define HTTP_GET_SAMPLING_TIME				2
#define HTTP_GET_OVERSAMPLING_RATIO			3
#define HTTP_GET_GAIN						4
#define HTTP_GET_SAMPLE_COUNT				5

#define HTTP_POST_RESOLUTION				6
#define HTTP_POST_SAMPLING_TIME				7
#define HTTP_POST_OVERSAMPLING_RATIO		8
#define HTTP_POST_GAIN						9
#define HTTP_POST_SAMPLE_COUNT				10
#define HTTP_GET_MEASUREMENTS				11
#define HTTP_GET_READ_AVERAGE				12
#define HTTP_GET_LED_STATUS					13
#define HTTP_POST_LED_STATUS				14
#define HTTP_GET_OFFSET_ENABLE				15
#define HTTP_GET_OFFSET_CALCULATE			16
#define HTTP_POST_OFFSET_ENABLE				17

#define DATA_SIZE	128

// --------------------------------------------------------------------------------------------------------------------

static const http_cmd_t http_control[] = {

		{.cmd="GET /ctr_resolution", .value = HTTP_GET_RESOLUTION},
		{.cmd="GET /ctr_sampling_time", .value = HTTP_GET_SAMPLING_TIME},
		{.cmd="GET /ctr_oversampling_ratio", .value = HTTP_GET_OVERSAMPLING_RATIO},
		{.cmd="GET /ctr_gain", .value = HTTP_GET_GAIN},
		{.cmd="GET /measurements", .value = HTTP_GET_MEASUREMENTS},
		{.cmd="GET /ctr_sample_count", .value = HTTP_GET_SAMPLE_COUNT},
		{.cmd="GET /ctr_read_average", .value = HTTP_GET_READ_AVERAGE},
		{.cmd="GET /ctr_led_status", .value = HTTP_GET_LED_STATUS},
		{.cmd="GET /ctr_offset_enable", .value = HTTP_GET_OFFSET_ENABLE},

		{.cmd="POST /ctr_blink_led", .value = HTTP_POST_CONTROL_BLINK_LED},
		{.cmd="POST /ctr_resolution", .value = HTTP_POST_RESOLUTION},
		{.cmd="POST /ctr_sampling_time", .value = HTTP_POST_SAMPLING_TIME},
		{.cmd="POST /ctr_oversampling_ratio", .value = HTTP_POST_OVERSAMPLING_RATIO},
		{.cmd="POST /ctr_gain", .value = HTTP_POST_GAIN},
		{.cmd="POST /ctr_sample_count", .value = HTTP_POST_SAMPLE_COUNT},
		{.cmd="POST /ctr_led_status", .value = HTTP_POST_LED_STATUS},
		{.cmd="POST /ctr_offset_enable", .value = HTTP_POST_OFFSET_ENABLE},
		{.cmd="GET /ctr_offset_calculate", .value = HTTP_GET_OFFSET_CALCULATE},
};

// --------------------------------------------------------------------------------------------------------------------

static void http_LED(led_select_t LED)
{
	if(bsp.led)
	{
		LED_osQueue(LED);
	}
}

// --------------------------------------------------------------------------------------------------------------------

static u32_t float_to_sampling_time(float value)
{
	u32_t select = (u32_t)(value * 10);
	switch (select)
	{
		case 15 : return ADC_SAMPLETIME_1CYCLE_5; break;
		case 25 : return ADC_SAMPLETIME_2CYCLES_5; break;
		case 85 : return ADC_SAMPLETIME_8CYCLES_5; break;
		case 165 : return ADC_SAMPLETIME_16CYCLES_5; break;
		case 325 : return ADC_SAMPLETIME_32CYCLES_5; break;
		case 645 : return ADC_SAMPLETIME_64CYCLES_5; break;
		case 3875 : return ADC_SAMPLETIME_387CYCLES_5; break;
		case 8105 : return ADC_SAMPLETIME_810CYCLES_5; break;
		default : return UINT32_MAX; break;
	}

	return UINT32_MAX;
}

// --------------------------------------------------------------------------------------------------------------------

static void http_measurements(struct netconn *conn)
{
    size_t size ;
    size_t sum = 0;

	if(pdTRUE == xSemaphoreTake(MeasMutex,  pdMS_TO_TICKS(20000)))
	{
		if(ADC_Measurement(bsp.adc.sample_count))
		{

			for (uint32_t i = 0; i < bsp.adc.sample_count; i++)
			{
				size = floatToString(buffer + sum, measurements[i]);
				sum +=size;
			}

			buffer[sum - 1] = 0;

			netconn_write(conn, buffer,strlen(buffer), NETCONN_NOCOPY);

		}

		xSemaphoreGive(MeasMutex);
	}
}


// --------------------------------------------------------------------------------------------------------------------

static void http_average(struct netconn *conn)
{
	float average = 0.0f;
	float tmp = 0.0f;

	char txt[12];
	memset(txt, 0, 12);

	if(pdTRUE == xSemaphoreTake(MeasMutex,  pdMS_TO_TICKS(20000)))
	{
		if(ADC_Measurement(bsp.adc.sample_count))
		{

			for (uint32_t i = 0; i < bsp.adc.sample_count ; i++)
			{
				tmp += measurements[i];
			}

			average = (float)(tmp/bsp.adc.sample_count);

			sprintf(txt, "%.6f", average);

			netconn_write(conn, txt,strlen(txt), NETCONN_NOCOPY);

		}

		xSemaphoreGive(MeasMutex);
	}
}

// --------------------------------------------------------------------------------------------------------------------

static float http_calc_offset_average(uint32_t sample_count)
{
	float average = 0.0f;
	float tmp = 0.0f;



	for (uint32_t i = 0; i < sample_count ; i++)
	{
		tmp += measurements[i];
	}

	average = (float)(tmp/sample_count);

	return average;
}

static void http_offset(struct netconn *conn)
{
	float average = 0.0f;

	char txt[12];
	memset(txt, 0, 12);

	uint32_t sample_size = ADC_DEF_SIZE;
	bool null_offset_state = bsp.adc.math_offset.enable;

	if(pdTRUE == xSemaphoreTake(MeasMutex, pdMS_TO_TICKS(20000)))
	{

	 bsp.adc.math_offset.enable = false;

		if(ADC_Measurement(sample_size))
		{

			bsp.adc.math_offset.zero[bsp.adc.gain.index] = -1.0f * http_calc_offset_average(sample_size);
			bsp.adc.math_offset.enable = null_offset_state;

			average = bsp.adc.math_offset.zero[bsp.adc.gain.index];

			sprintf(txt, "%.6f", average);

			netconn_write(conn, txt,strlen(txt), NETCONN_NOCOPY);
		}

		bsp.adc.math_offset.enable = null_offset_state;
		xSemaphoreGive(MeasMutex);

	}
}

// --------------------------------------------------------------------------------------------------------------------
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

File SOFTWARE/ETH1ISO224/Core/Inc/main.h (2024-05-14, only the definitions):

#define MCU_DEFAULT_Pin LL_GPIO_PIN_2
#define MCU_DEFAULT_GPIO_Port GPIOE
#define MCU_G100_Pin LL_GPIO_PIN_3
#define MCU_G100_GPIO_Port GPIOA
#define MCU_G10_Pin LL_GPIO_PIN_4
#define MCU_G10_GPIO_Port GPIOA
#define MCU_G1_Pin LL_GPIO_PIN_5
#define MCU_G1_GPIO_Port GPIOA
#define MCU_ZOFFS_Pin LL_GPIO_PIN_6
#define MCU_ZOFFS_GPIO_Port GPIOA
#define LED_BLUE_Pin LL_GPIO_PIN_6
#define LED_BLUE_GPIO_Port GPIOC
#define LED_GREEN_Pin LL_GPIO_PIN_8
#define LED_GREEN_GPIO_Port GPIOC
#define LED_RED_Pin LL_GPIO_PIN_9
#define LED_RED_GPIO_Port GPIOC
#define EEPROM_nWP_Pin LL_GPIO_PIN_5
#define EEPROM_nWP_GPIO_Port GPIOB

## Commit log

2024-04-26 Hardware design
    [Analog.kicad_sch, ETH1ISO224.kicad_pcb, ETH1ISO224.kicad_sch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]
2024-04-28 Hardware design done
    [Analog.kicad_sch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]
2024-04-28 Footprint change, not critical
    [ETH1ISO224.kicad_pcb, MCU.kicad_sch]
2024-05-04 Changed REF19 to REF20
    [Analog.kicad_sch, ETH1ISO224.kicad_sch, Ethernet.kicad_sch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]
2024-05-06 Hardware changes
    [ETH1ISO224.kicad_pcb]
2024-05-08 Software development
    [Analog.kicad_sch, ETH1ISO224.kicad_pcb]
2024-05-12 PCB changes
    [ETH1ISO224.kicad_pcb]
2024-05-19 Fixes in null offset
    [ADC.c, ETH1ISO224.ioc, SCPI_Def.c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]
2024-05-21 Added new SCPI commands. Bug fixes.
    [ADC.c, BSP.h, SCPI_Calibration.c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]
2024-05-22 Added TIM3 timer for LED status blink. Changes in SCPI commands.

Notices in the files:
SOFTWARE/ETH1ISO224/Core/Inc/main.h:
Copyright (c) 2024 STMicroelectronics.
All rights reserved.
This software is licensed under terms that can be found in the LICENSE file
